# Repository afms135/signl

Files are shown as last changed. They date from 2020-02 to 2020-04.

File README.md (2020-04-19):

<p align="center">
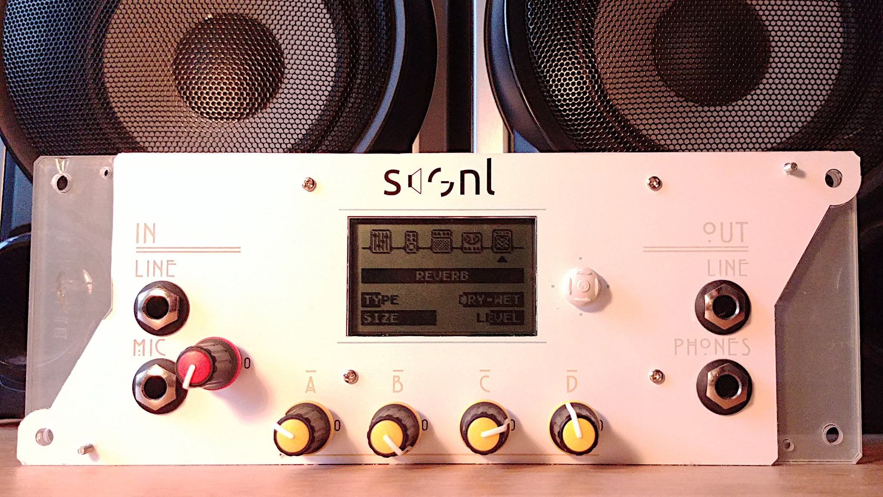
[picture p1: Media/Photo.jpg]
  
</p>

# signl - An Open Source Real-Time Audio Effects Processor running on Raspberry Pi



*signl* is an audio effects processor developed to provide an open-source (modifiable and extendable), real-time (no noticable playing latency), low-cost (Raspberry Pi based) standalone unit for musicians. Development started at the University of Glasgow for ENG5220: Real Time Embedded Programming 2019-2020.

The main features are:

* Mic or Line level in
* Line and Headphone out
* Up to five serial audio effects
* Real time parameter control of each effect
* Easy to understand GUI
* Half rack size

## Video Walkthrough

<p align="center">
  <a href="https://youtu.be/WcyoIrp74zg">
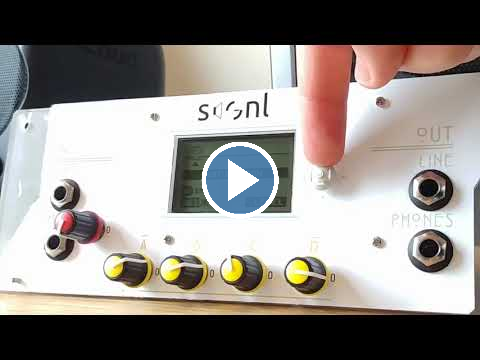
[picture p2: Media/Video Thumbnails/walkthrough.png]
  
  </a>
</p>

## Documentation

See our [Github wiki](https://github.com/afms135/signl/wiki) for detailed instructions on how to reproduce the system, as well as information about the design of the system. Detailed software documentation can be found in the [Doxygen documentation](https://afms135.github.io/signl/).

## Social Media

- [Twitter](https://twitter.com/signlHW)
- [Youtube](https://www.youtube.com/channel/UChTp4nFLsnpuzNy29fdVIeA)

## Authors and Individual Contributions

- Alexander Strachan (afms135, 2173868s) - Software Architect:  wrote hardware/JACK interface code, effect plugin system and two effects (amplifier, overdrive).
- Robert Norris (robnorr, 2198915n) - Software: Wrote GUI code (including tuner), five effects (EQ, Noise Gate, Reverb, Saturation, Vinyl), performed tests and generated data for the wiki. Contributed to the social media promotion.
- Simon Ridley (ithinkitssimon, 2187742r) - Hardware: Designed electronics and mechanical aspects of project, wrote tremolo plugin, documented relevant aspects and contributed to social media of project.

## COVID-19

The project hardware was completed before the 15th of March, so this did not prevent completion of the project, however the full project enclosure could not be manufactured. The designs for this enclosure have been included.

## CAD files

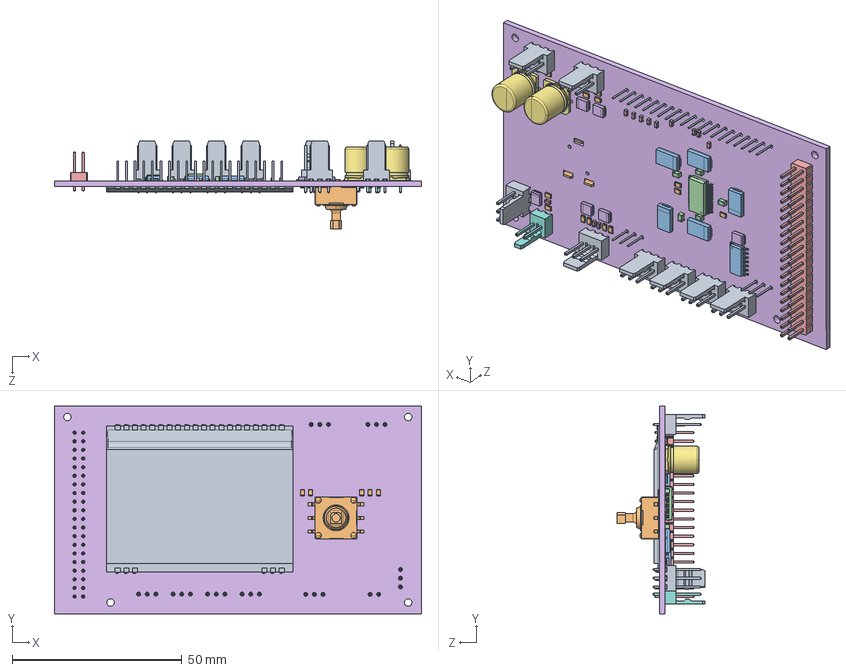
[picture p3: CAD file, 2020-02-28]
Hardware/Enclosure/Hardware.SLDASM
108.1 x 61.1 x 25.8 mm
COMPOUND.step
SOLID.step x 20
SOLID-0.step x 5
SOLID-1.step x 5
SOLID-2.step x 12
SOLID-3.step x 6
SOLID-4.step x 2
SOLID-5.step
SOLID-6.step x 8
SOLID-7.step
SOLID-8.step
SOLID-9.step
SOLID-10.step
COMPOUND-11.step

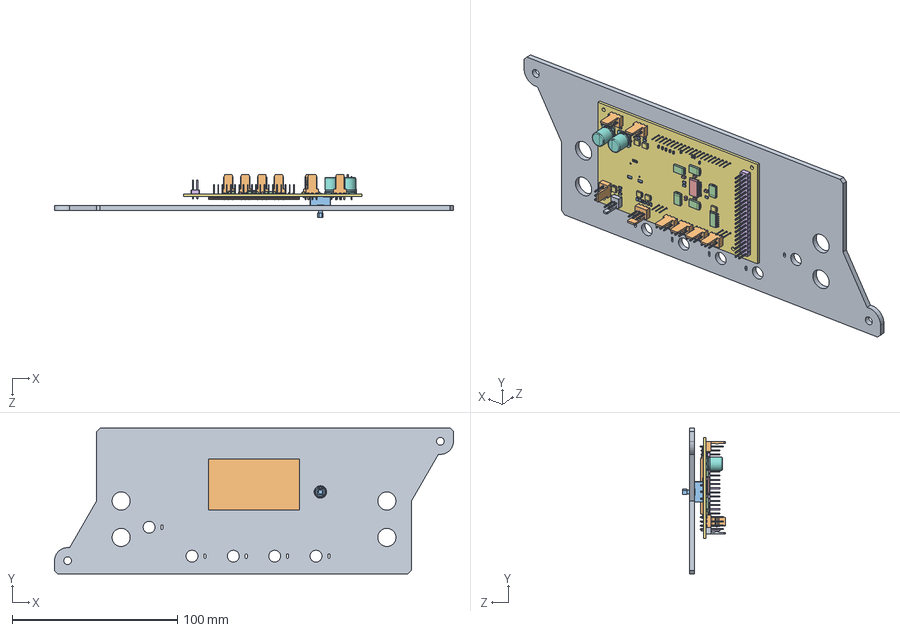
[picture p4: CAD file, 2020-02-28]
Hardware/Enclosure/Enclosure.SLDASM
241.3 x 88.1 x 25.8 mm
Faceplate
COMPOUND.step
SOLID.step x 20
SOLID-0.step x 5
SOLID-1.step x 5
SOLID-2.step x 12
SOLID-3.step x 6
SOLID-4.step x 2
SOLID-5.step
SOLID-6.step x 8
SOLID-7.step
SOLID-8.step
SOLID-9.step
SOLID-10.step
COMPOUND-11.step

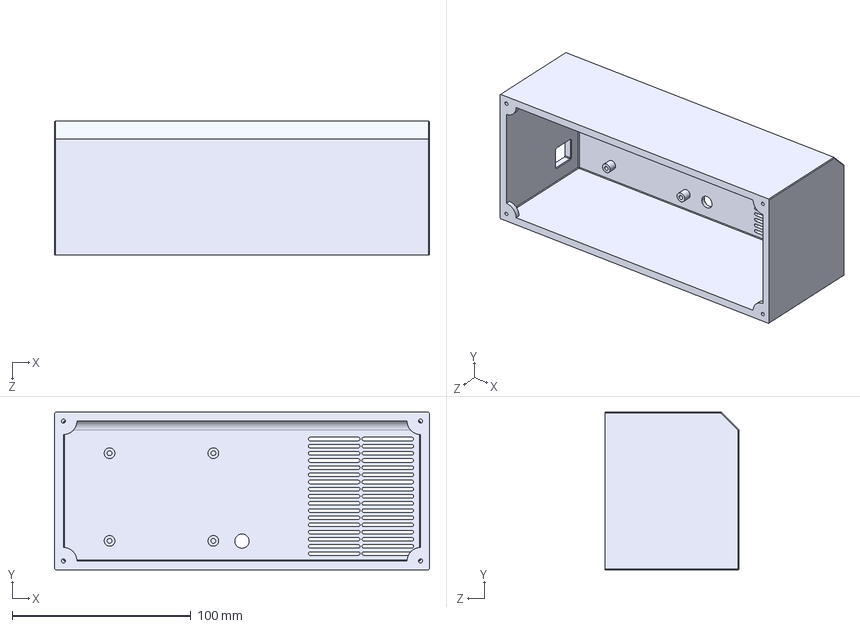
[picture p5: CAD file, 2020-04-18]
Hardware/Enclosure/Box.STEP
209.5 x 88.1 x 75.0 mm

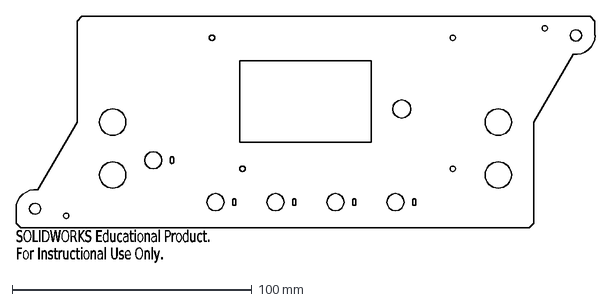
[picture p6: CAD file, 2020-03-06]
Hardware/Enclosure/FaceplateFRONT.DXF
SOLIDWORKS Educational Product.
For Instructional Use Only.

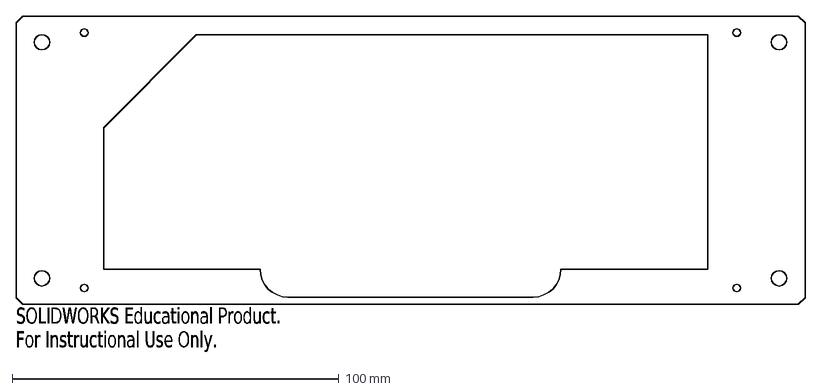
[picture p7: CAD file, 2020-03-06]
Hardware/Enclosure/FaceplateBACK.DXF
SOLIDWORKS Educational Product.
For Instructional Use Only.

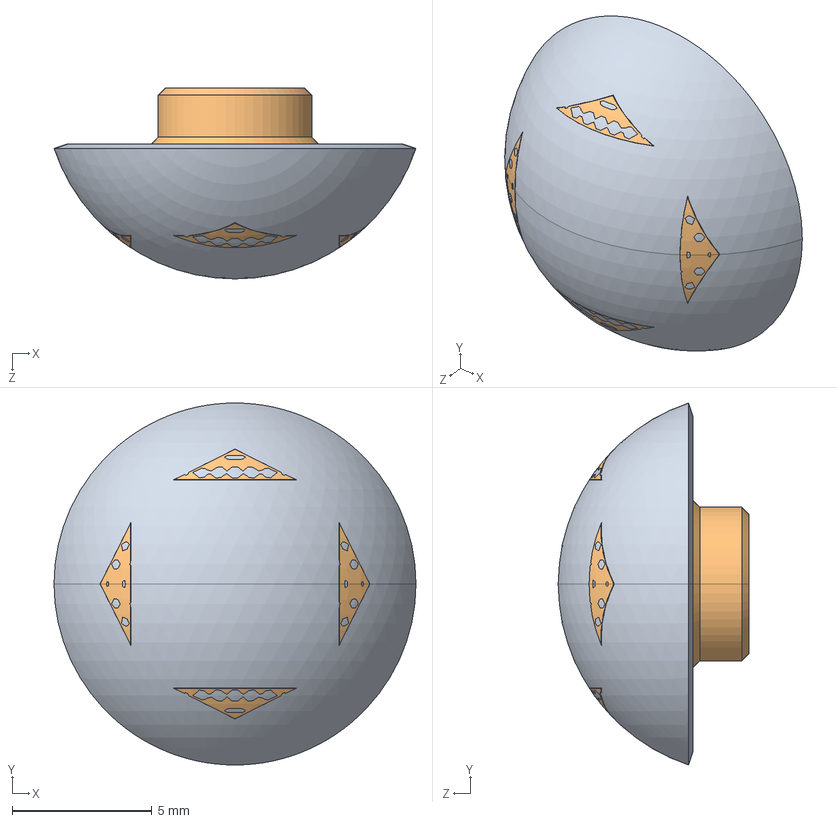
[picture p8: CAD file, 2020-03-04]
Hardware/Enclosure/JoystickButton.STEP
12.9 x 12.9 x 6.82 mm

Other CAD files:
Hardware/Enclosure/Faceplate.SLDPRT
Hardware/Enclosure/Box.SLDPRT
Hardware/Enclosure/Box.STL
Hardware/Enclosure/JoystickButton.SLDPRT
Hardware/Enclosure/JoystickButton.STL

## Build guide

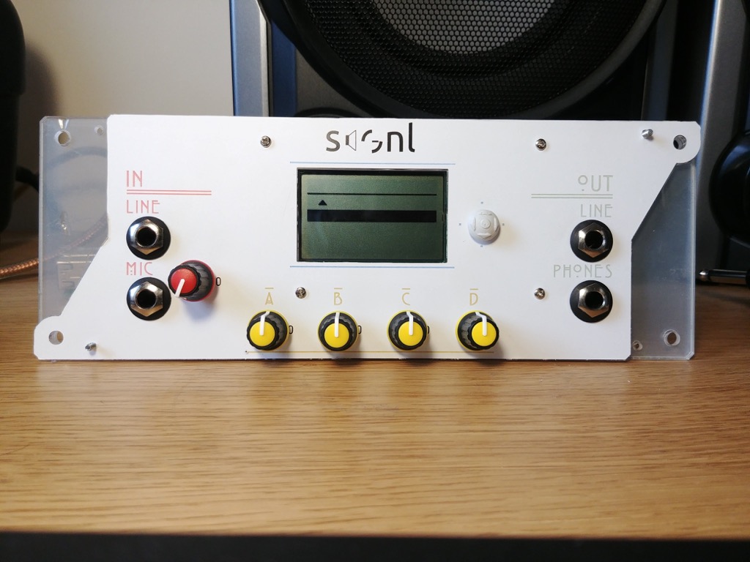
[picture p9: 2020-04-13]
Media/User Guide/user00b.jpg

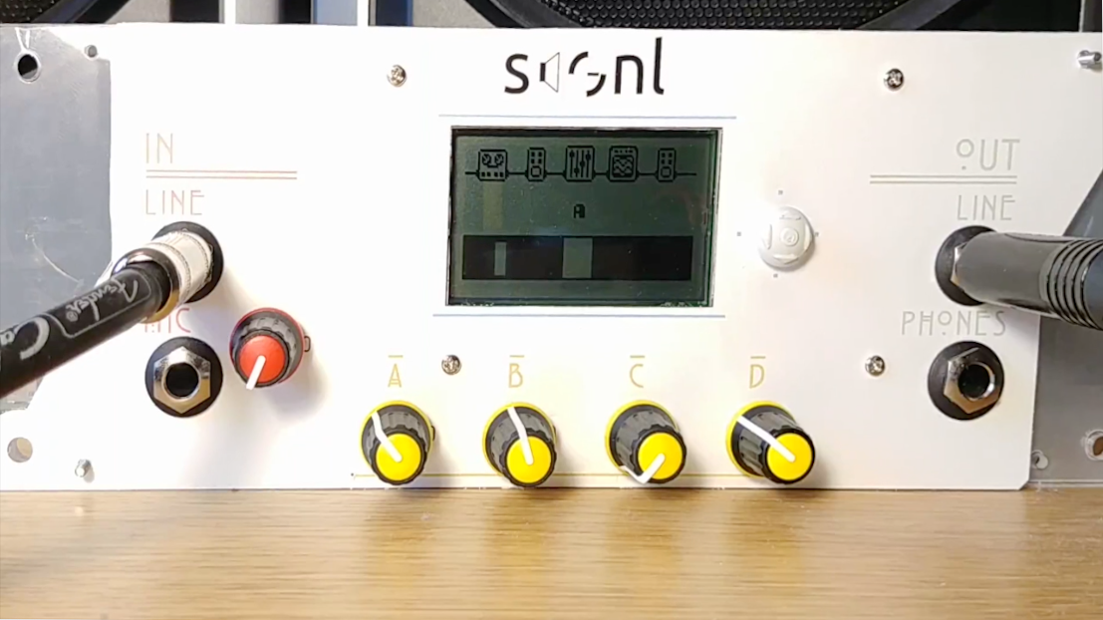
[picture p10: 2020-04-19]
Media/User Guide/user11.png

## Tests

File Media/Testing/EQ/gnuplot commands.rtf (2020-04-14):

plot "< paste L_FFT RAW_FFT" using 1:($2-$4) with filledcurve x1 linecolor "0x7Fd7191c", \
"< paste LM_FFT RAW_FFT" using 1:($2-$4) with filledcurve x1 linecolor "0x5Ffdae61", \
"< paste HM_FFT RAW_FFT" using 1:($2-$4) with filledcurve x1 linecolor "0x5fabdda4", \
"< paste H_FFT RAW_FFT" using 1:($2-$4) with filledcurve x1 linecolor "0x7F2b83ba"

set label "LOW" at 50,12 front textcolor "0xd7191c"
set label "LOW-MID" at 165,12 front textcolor "0xdd8e51"
set label "HIGH-MID" at 650,12 front textcolor "0x8bbd84"
set label "HIGH" at 3500,12 front textcolor "0x2b83ba"

plot “< paste FULL_FFT RAW_FFT" using 1:($2-$4) with filledcurve x1 linecolor "0x9FB8DE29”, \
“< paste FLAT_FFT RAW_FFT" using 1:($2-$4) with filledcurve x1 linecolor "0x3F404788"

set label "Default paramters" at 25,-10 front textcolor "0x202748"
set label "Full parameters" at 25,2 front textcolor "0x384E09"

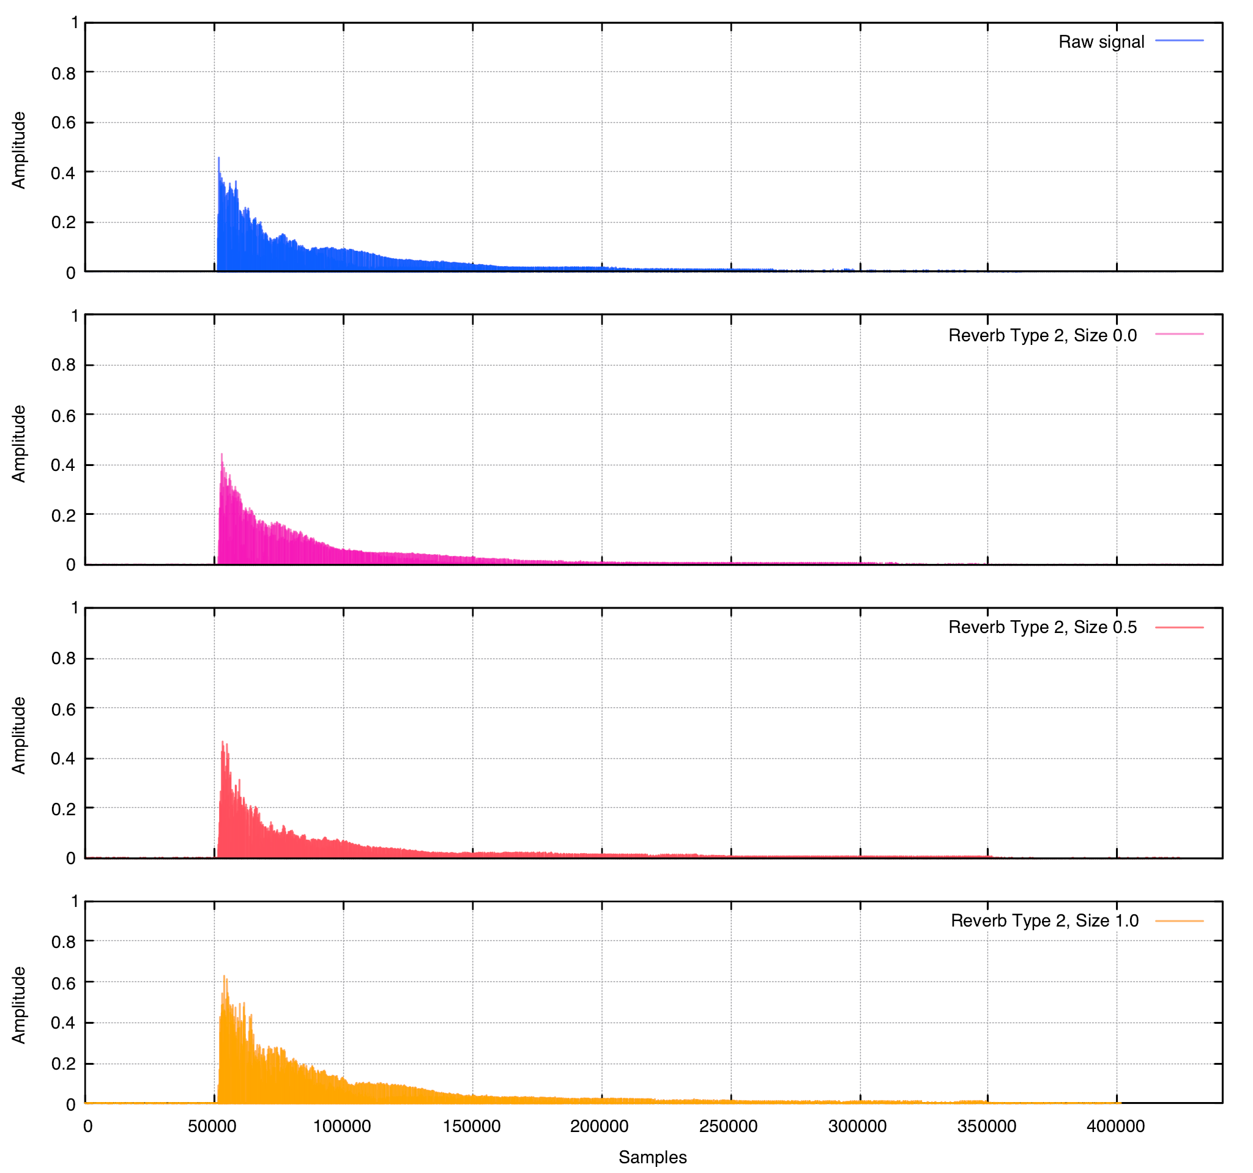
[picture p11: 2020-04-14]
Media/Testing/Reverb/Type2.png

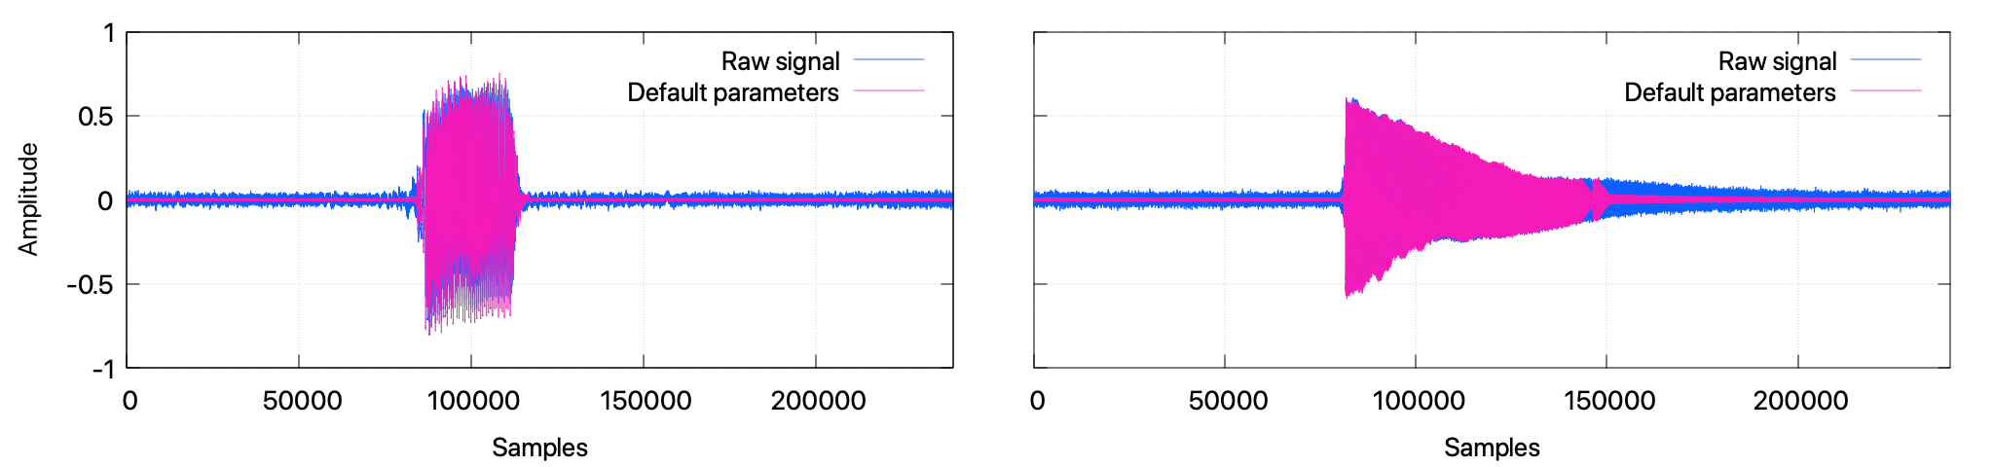
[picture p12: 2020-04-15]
Media/Testing/Noise Gate/DEF.png

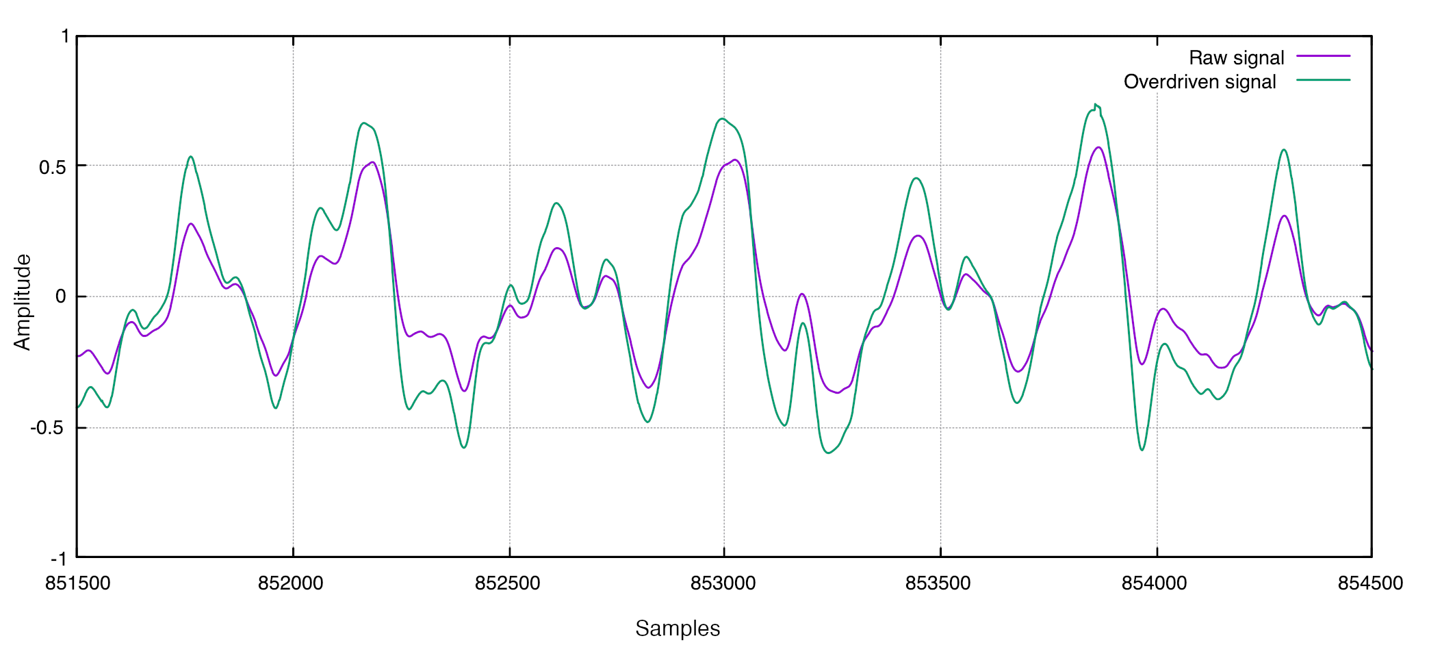
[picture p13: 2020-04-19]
Media/Testing/Overdrive/Guitar1.png

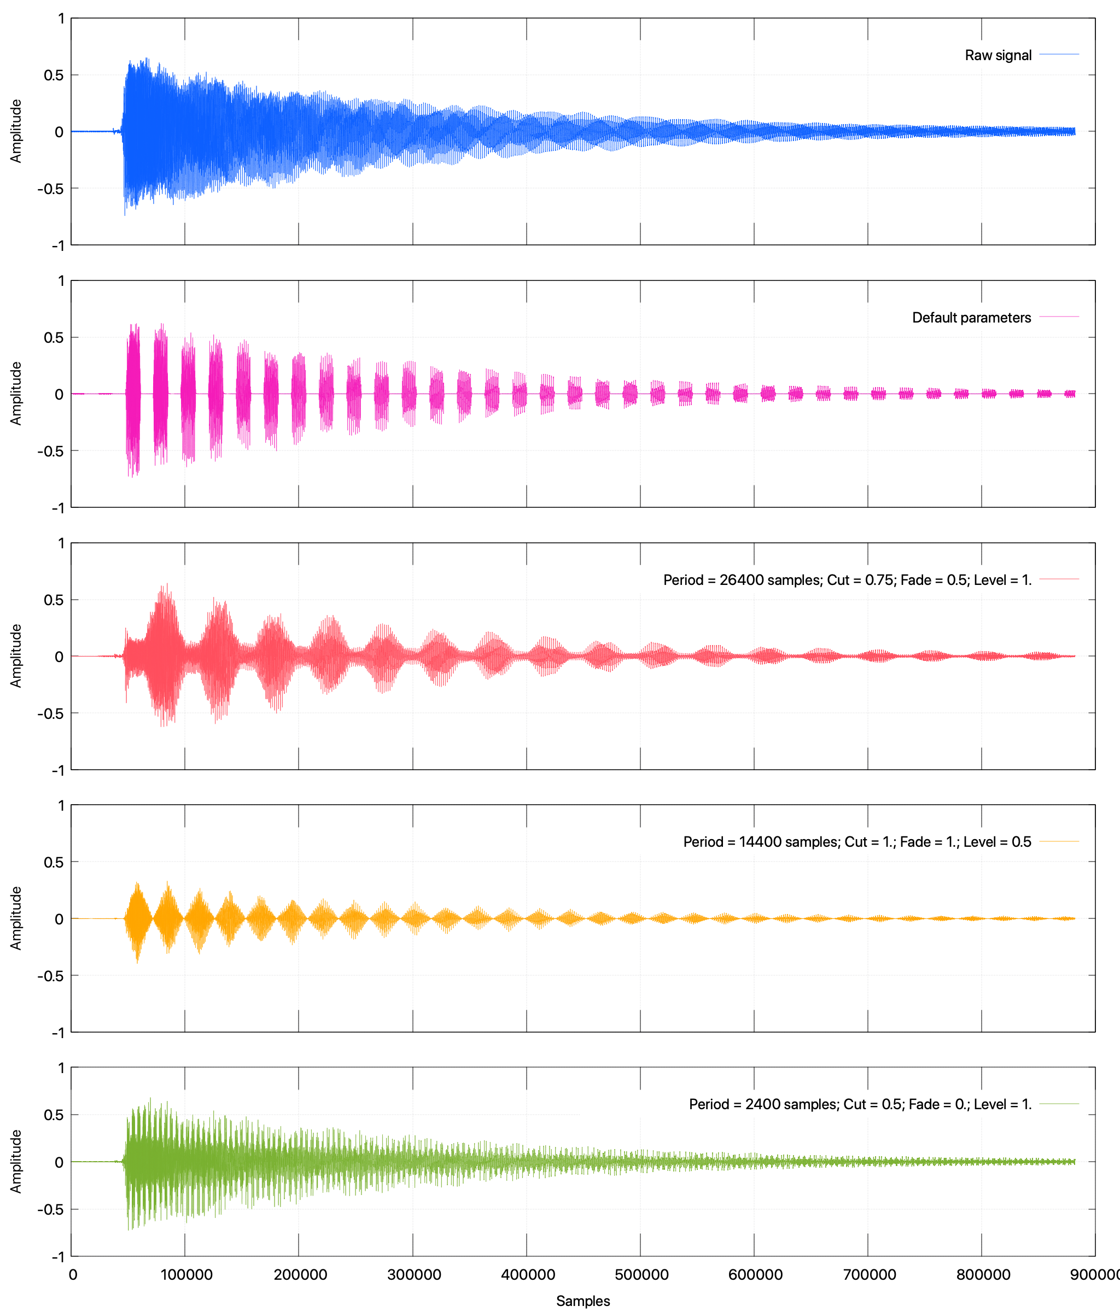
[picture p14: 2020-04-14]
Media/Testing/Tremolo/Plots.png

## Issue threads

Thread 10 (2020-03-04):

Tuner plugin

robnorr, 2020-03-04:
not sure how possible

robnorr, 2020-03-28:
Maybe better if made as another screen - via pushing the button

robnorr, 2020-04-18:
Achieved via af4ef87c2833d9f289b5b653fc9419dccaee8651
Written as a 3rd disply state (after param_view and level_view). Has a resolution of 1.46Hz

robnorr, 2020-04-18:
Not merging to master as it isn't really a useful implementation. Video and description on Wiki [here](https://github.com/afms135/signl/wiki/Tuner).

afms135, 2020-04-18:
Just copying what i said [Here](https://github.com/afms135/signl/commit/af4ef87c2833d9f289b5b653fc9419dccaee8651#comments) not sure if you get notifications.

Shouldn't line 193 of signl.cpp read fft.fft(tuner_array, fft_re.data(), fft_im.data()); You are filling tuner_array but not using it?

Would that fix the segfault?

robnorr, 2020-04-18:
Good catch! It definitely should be `fft.fft(tuner_array, ...`

But it deosn't seem to fix the segfault.

robnorr, 2020-04-18:
a5d5e1dc2916b91e8277dcb96f08fcf834b55c6b
Added gaussian interpolation and windowing inspired from [this paper](http://cds.cern.ch/record/738182/files/ab-2004-023).
Need to write up wiki (and record a demonstration video) and check that all relevant Doxygen documentation is done.

robnorr, 2020-04-19:
Closed by 7fdb2a437a745f4626878dc81359b5585256b6f4

Closed 2020-04-19.

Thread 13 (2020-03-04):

Noise gate plugin

robnorr, 2020-03-04:
Params:
Threshold
Attack
Release
Cut level

robnorr, 2020-03-08:
Closed by b7b99cb10c4ba1331b7fe238a065dc8c83ba6568

Closed 2020-03-08.

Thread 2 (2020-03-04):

EQ plugin

afms135, 2020-03-04:
Add an 4-band? equalizer plugin.

robnorr, 2020-03-04:
Or could be 3-band with the fourth parameter being the mid-freqency

robnorr, 2020-03-31:
Closed by d951ab6a34f3c8e1103f7d8e63b02f41674feea6

robnorr, 2020-03-31:
If anyone wants to reopen this issue, I believe there is a slight bump at the filter overlaps - all filters are 1st order butterworth, the xover frequencies are (150Hz, 300Hz, 3kHz). 'Low' is a lowpass, 'High' is a highpass, and the other two are bandpass. So, if there is more work to be done on this plugin, can look at the frequency response of all the filters, but for now - it works.

Closed 2020-03-31.

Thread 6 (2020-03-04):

Store current effect parameters

robnorr, 2020-03-04:
If user switches a plugin for another one, then switches back, we don't want them to have lost the parameters they had put in previously.

robnorr, 2020-03-04:
This should also help with presets if we end up doing that.

robnorr, 2020-03-20:
Have somewhat fixed this with a6fb38cac325e3de6108d7da31902e091f61844e and 34ad3bb21003db3555e952cdbe3c1dfca51d5a70

Closed 2020-04-14.

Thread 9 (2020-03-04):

Tremolo plugin

robnorr, 2020-03-04:
Params:
Rate
Depth
Fade
Level

ithinkitssimon, 2020-04-09:
Started new branch for tremolo plugin.

robnorr, 2020-04-09:
Period and cut work, but fade is broken.

ithinkitssimon, 2020-04-09:
Closed by cde07c1253e88e85d771904e55b5b538eec5e8da

Closed 2020-04-09.

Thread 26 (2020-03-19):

JACK crashing on entry

robnorr, 2020-03-19:
Wasn't doing this before - can't see any changes hardware wise. Tried power cycle with same thing happening. Any ideas?

Ouput log

```
pi@raspberrypi:~ $ JACK_NO_AUDIO_RESERVATION=1 jackd -P75 -dalsa -dhw:0 -r48000 -p256 -n2
jackdmp 1.9.12
Copyright 2001-2005 Paul Davis and others.
Copyright 2004-2016 Grame.
Copyright 2016-2017 Filipe Coelho.
jackdmp comes with ABSOLUTELY NO WARRANTY
This is free software, and you are welcome to redistribute it
under certain conditions; see the file COPYING for details
JACK server starting in realtime mode with priority 75
self-connect-mode is "Don't restrict self connect requests"
creating alsa driver ... hw:0|hw:0|256|2|48000|0|0|nomon|swmeter|-|32bit
configuring for 48000Hz, period = 256 frames (5.3 ms), buffer = 2 periods
ALSA: final selected sample format for capture: 32bit integer little-endian
ALSA: use 2 periods for capture
ALSA: final selected sample format for playback: 32bit integer little-endian
ALSA: use 2 periods for playback
ALSA: poll time out, polled for 7999098 usecs
JackAudioDriver::ProcessAsync: read error, stopping...
```

robnorr, 2020-03-19:
Update - doesn't do it every time. Works sometimes but not always.

robnorr, 2020-03-25:
This is getting worse. Jackd almost always crashes, always with the same output log as above, but I can't figure out what is different when it works - seems totally random. Getting very hard to get any work done when I can't get any audio out.

Very rarely, when jackd doesn't crash straight away (after its 8sec timeout), I can run the signl software, but then often it just crashes: sometimes when I do something like change an effect; sometimes just randomly.

Have tried various alsamixer settings, but they don't appear to make any difference - have tried both line in and mic in as the input mux but same timeout error occurs. Have tried different jackd buffer sizes, periods, etc. - the only thing that changes is that the period length seems proportional to the timeout.

robnorr, 2020-03-26:
Seems it was a hardware issue - intermittent connection to the external crystal. Working now.

Closed 2020-03-26.

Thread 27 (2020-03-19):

ADC values return 0

robnorr, 2020-03-19:
Have checked voltage on the pins of the ADC (MCP3004) - they are what they should be. But the SPI transfer is returning 0 no matter what.

ithinkitssimon, 2020-03-19:
Have you checked CS line?

afms135, 2020-03-20:
Try reducing the SPI clock rate to 1000000 (or lower).
I think 2000000 might be to high (line 4 of adc.cpp).

robnorr, 2020-03-20:
> Have you checked CS line?

On program start up, chip select goes high, then low. The first value read from the ADC works properly, but the chip select never goes high again therefore the rest of the values read are all 0.

So, need to figure out why the chip select line is getting stuck low.

robnorr, 2020-03-20:
Closed by 1cb5aca4819267a3845c9bf30a77d94539ea7d11

Closed 2020-03-20.

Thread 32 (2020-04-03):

Buffer based

robnorr, 2020-04-03:
Tried to send audio buffers straight from jack to each plugin as it's the more normal way of operating when doing audio stuff. But mainly tried it to halve the latency of the convolution plugin.

Tried on a new branch here bd3dcbe66a859814dcbf2434dfa134225c111fe3

And while it compiles and runs - can even see that audio is going through properly - the line out is silent. No idea why.

afms135, 2020-04-03:
This doesn't work because the `*out` pointer that jack gives us is a buffer that you need to _write_ into.
So swapping the pointers like in the null plugin won't work. Basically the operator signiture would need to be changed to `void operator()(float *in, float *out, unsigned int frames)` and the jack->signl callback
would need to be changed to `virtual void process(sample_t* in, sample_t *out, jack_nframes_t frames) = 0;`

robnorr, 2020-04-03:
That makes sense. I've decided it's fine to leave it as it is (non-buffer based), because it gives more flexibility to those plugins that do need buffers (i.e. convolution) over the buffer size etc. At the cost of double latency, but that's okay for now, and probably will be forever (I hope)

afms135, 2020-04-10:
Should we close this? It can always be reopened if necessary.

Closed 2020-04-10.

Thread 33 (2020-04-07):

Deleting the reverb plugin crashes the signl software

robnorr, 2020-04-07:
If the reverb plugin is being used (see 7ae3209015648144f1a2c41f5cef258c4c02af92 ), and is then deleted (i.e., switched out for another plugin), the signl software crashes and stops, with this being spat out on the terminal:

    signl: ../FFTConvolver/Utilities.cpp:61: void fftconvolver::ComplexMultiplyAccumulate(fftconvolver::SplitComplex&, const fftconvolver::SplitComplex&, const fftconvolver::SplitComplex&): Assertion `result.size() == b.size()' failed.
    Aborted

My guess is that the FFTConvolver object(s) which are created in the reverb plugin aren't destroyed properly, but I can't figure out how to destroy them properly.

afms135, 2020-04-07:
Reorder the classes private members, they are destructed in reverse order. The problem probably is the std::vectors are being destroyed before the FFTConvolvers, so try placing the convolves last.

afms135, 2020-04-07:
See a80ed9f68adab00561acb64b48f637278658d37a

robnorr, 2020-04-07:
Okay, odd behaviour now. Have made the change you suggested, and the problem is fixed for the first time that I switch out the reverb plugin (i.e. it no longer crashes). But, if the plugin is put back in, this time (and for every time after) when I switch it out, it crashes the same way as before.

robnorr, 2020-04-07:
Note, sometimes it crashes with `Segmentation fault` rather than the above message.

robnorr, 2020-04-07:
Okay, I tried with just one FFTConvolver at a time and it seems like it was the big long church IR (131,072 samples) that was causing problems. The smaller IR (16,384 samples) on its own never crashes.

robnorr, 2020-04-07:
Using the TwoStageFFTConvolver has greatly improved this. Still crashes sometimes, but FAR less often.

afms135, 2020-04-07:
Maybe try changing the type of the impulse arrays to const float[] instead of a vector. But my gut feeling for a long term fix is to compile the fftconvolver code _into_ the so file instead of using dlopen() to load it into the main executable. That would require a makefile change, but I'd rather wait until the plugin is finished before doing that.

robnorr, 2020-04-07:
Seems pretty stable now. Can only make it crash by switching between the reverb and some other effect really fast repeatedly. But what you say might help, so I'll let you know when I've finished the rest of the plugin

robnorr, 2020-04-08:
Reverb plugin is finished and ready to be merged as of e27cc37cb5b124e46912d815ed9ad1e6a67f0beb .

It only crashes if you switch it out within ~1 sec of switching onto it, but other than that it's perfect.
@afms135 would you rather I merge to master now, or do you want to make any changes in the branch?

afms135, 2020-04-08:
Do the merge now, I'll do my work later.

afms135, 2020-04-14:
Fixed by 7207acab2960d0daf7a8058055e3c33809f3bd66

Closed 2020-04-14.

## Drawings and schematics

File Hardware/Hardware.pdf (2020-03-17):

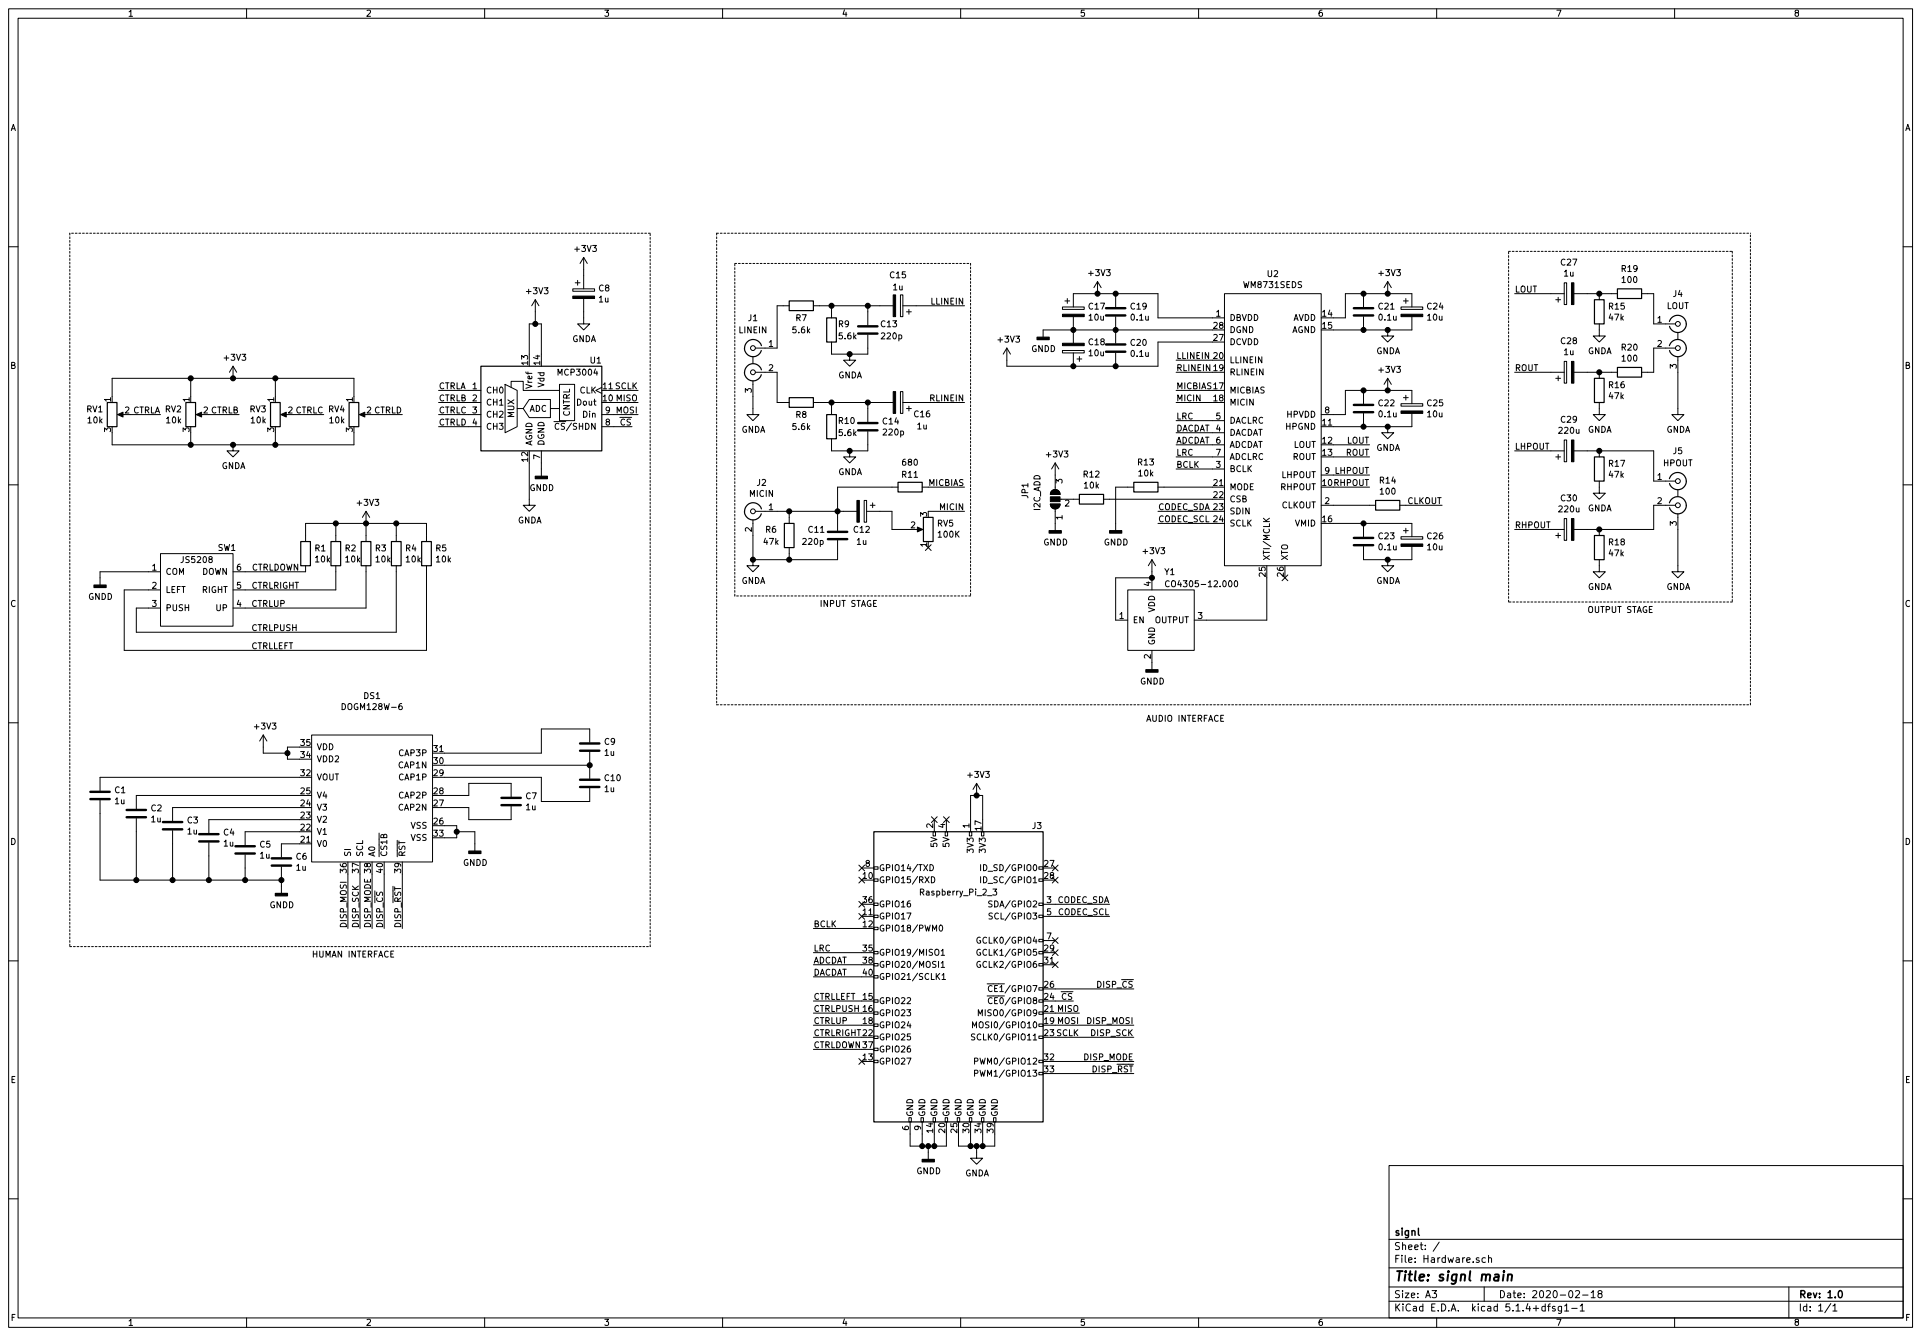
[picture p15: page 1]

7 CS/SHDN 8 Din 9 U1 MCP3004 +3V3 GNDD

LRC MICIN
LRC
LHPOUT LOUT ROUT DACDAT ADCDAT

AUDIO INTERFACE HUMAN INTERFACE

CTRLRIGHT CTRLUP CTRLLEFT CTRLPUSH

File: Hardware.sch Sheet: / signl

Id: 1/1 Title: signl main

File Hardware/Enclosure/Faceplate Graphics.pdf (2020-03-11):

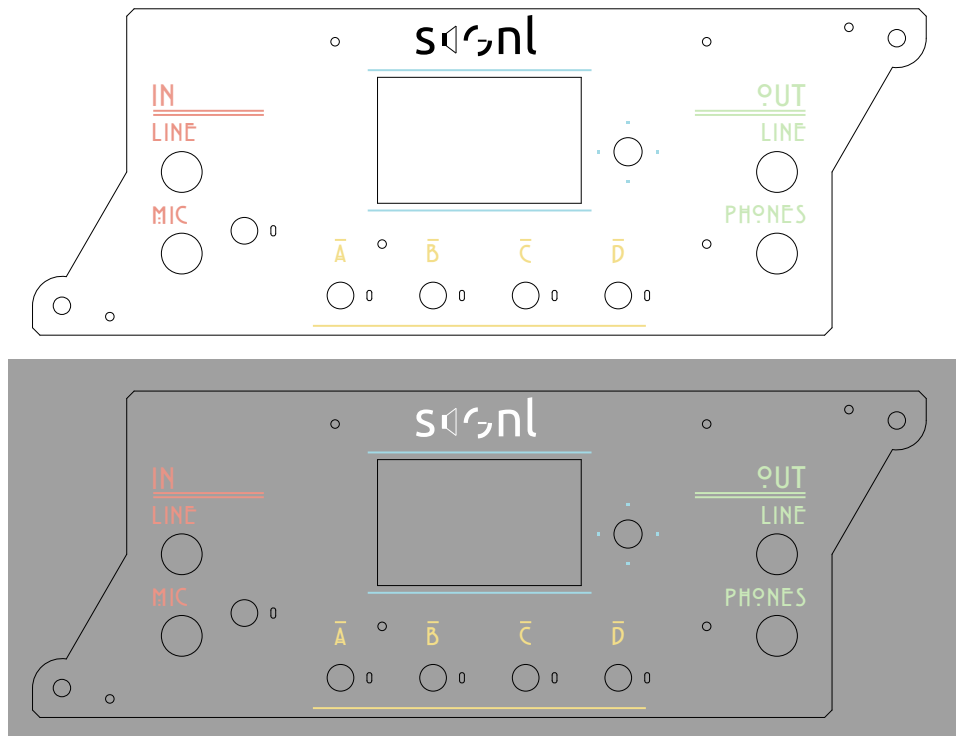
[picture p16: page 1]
LINE; MIC; PHONES A; OUT

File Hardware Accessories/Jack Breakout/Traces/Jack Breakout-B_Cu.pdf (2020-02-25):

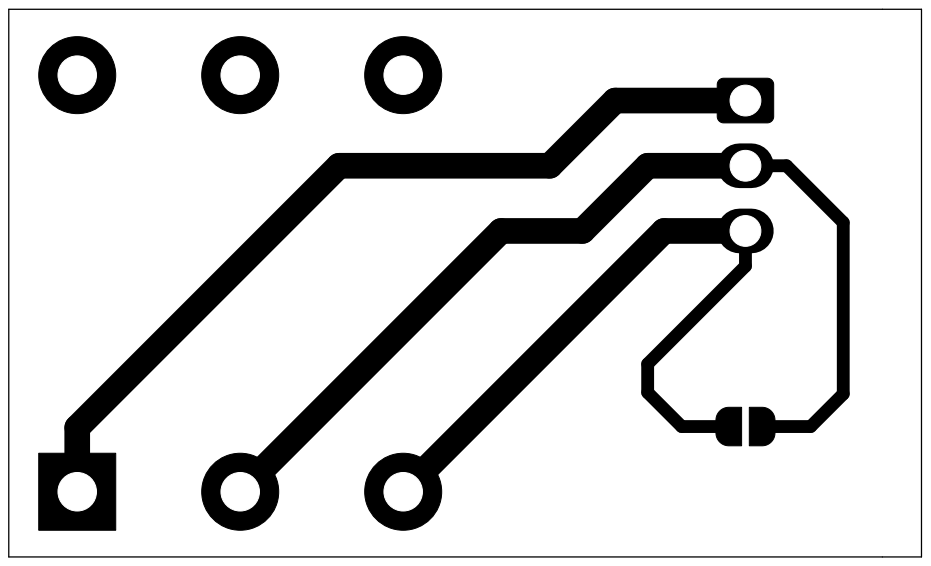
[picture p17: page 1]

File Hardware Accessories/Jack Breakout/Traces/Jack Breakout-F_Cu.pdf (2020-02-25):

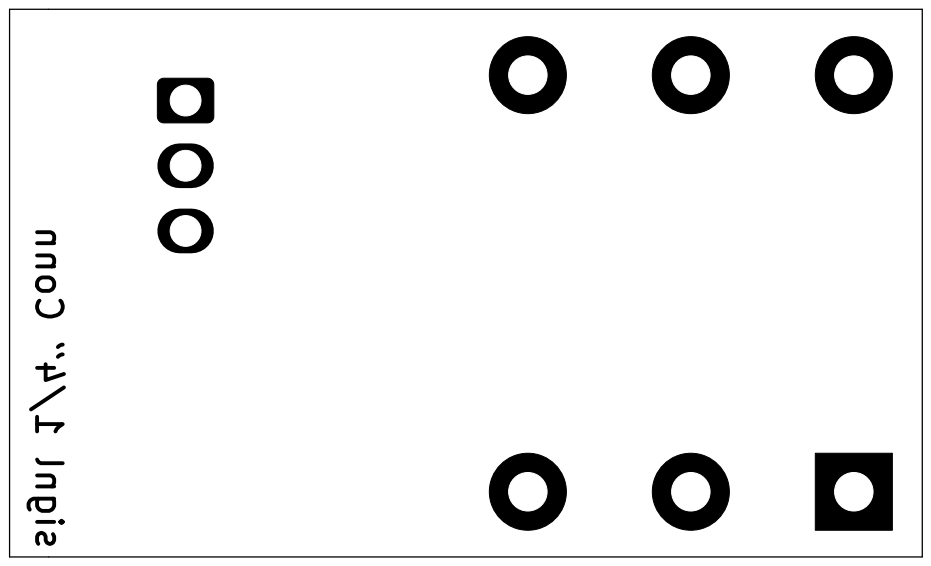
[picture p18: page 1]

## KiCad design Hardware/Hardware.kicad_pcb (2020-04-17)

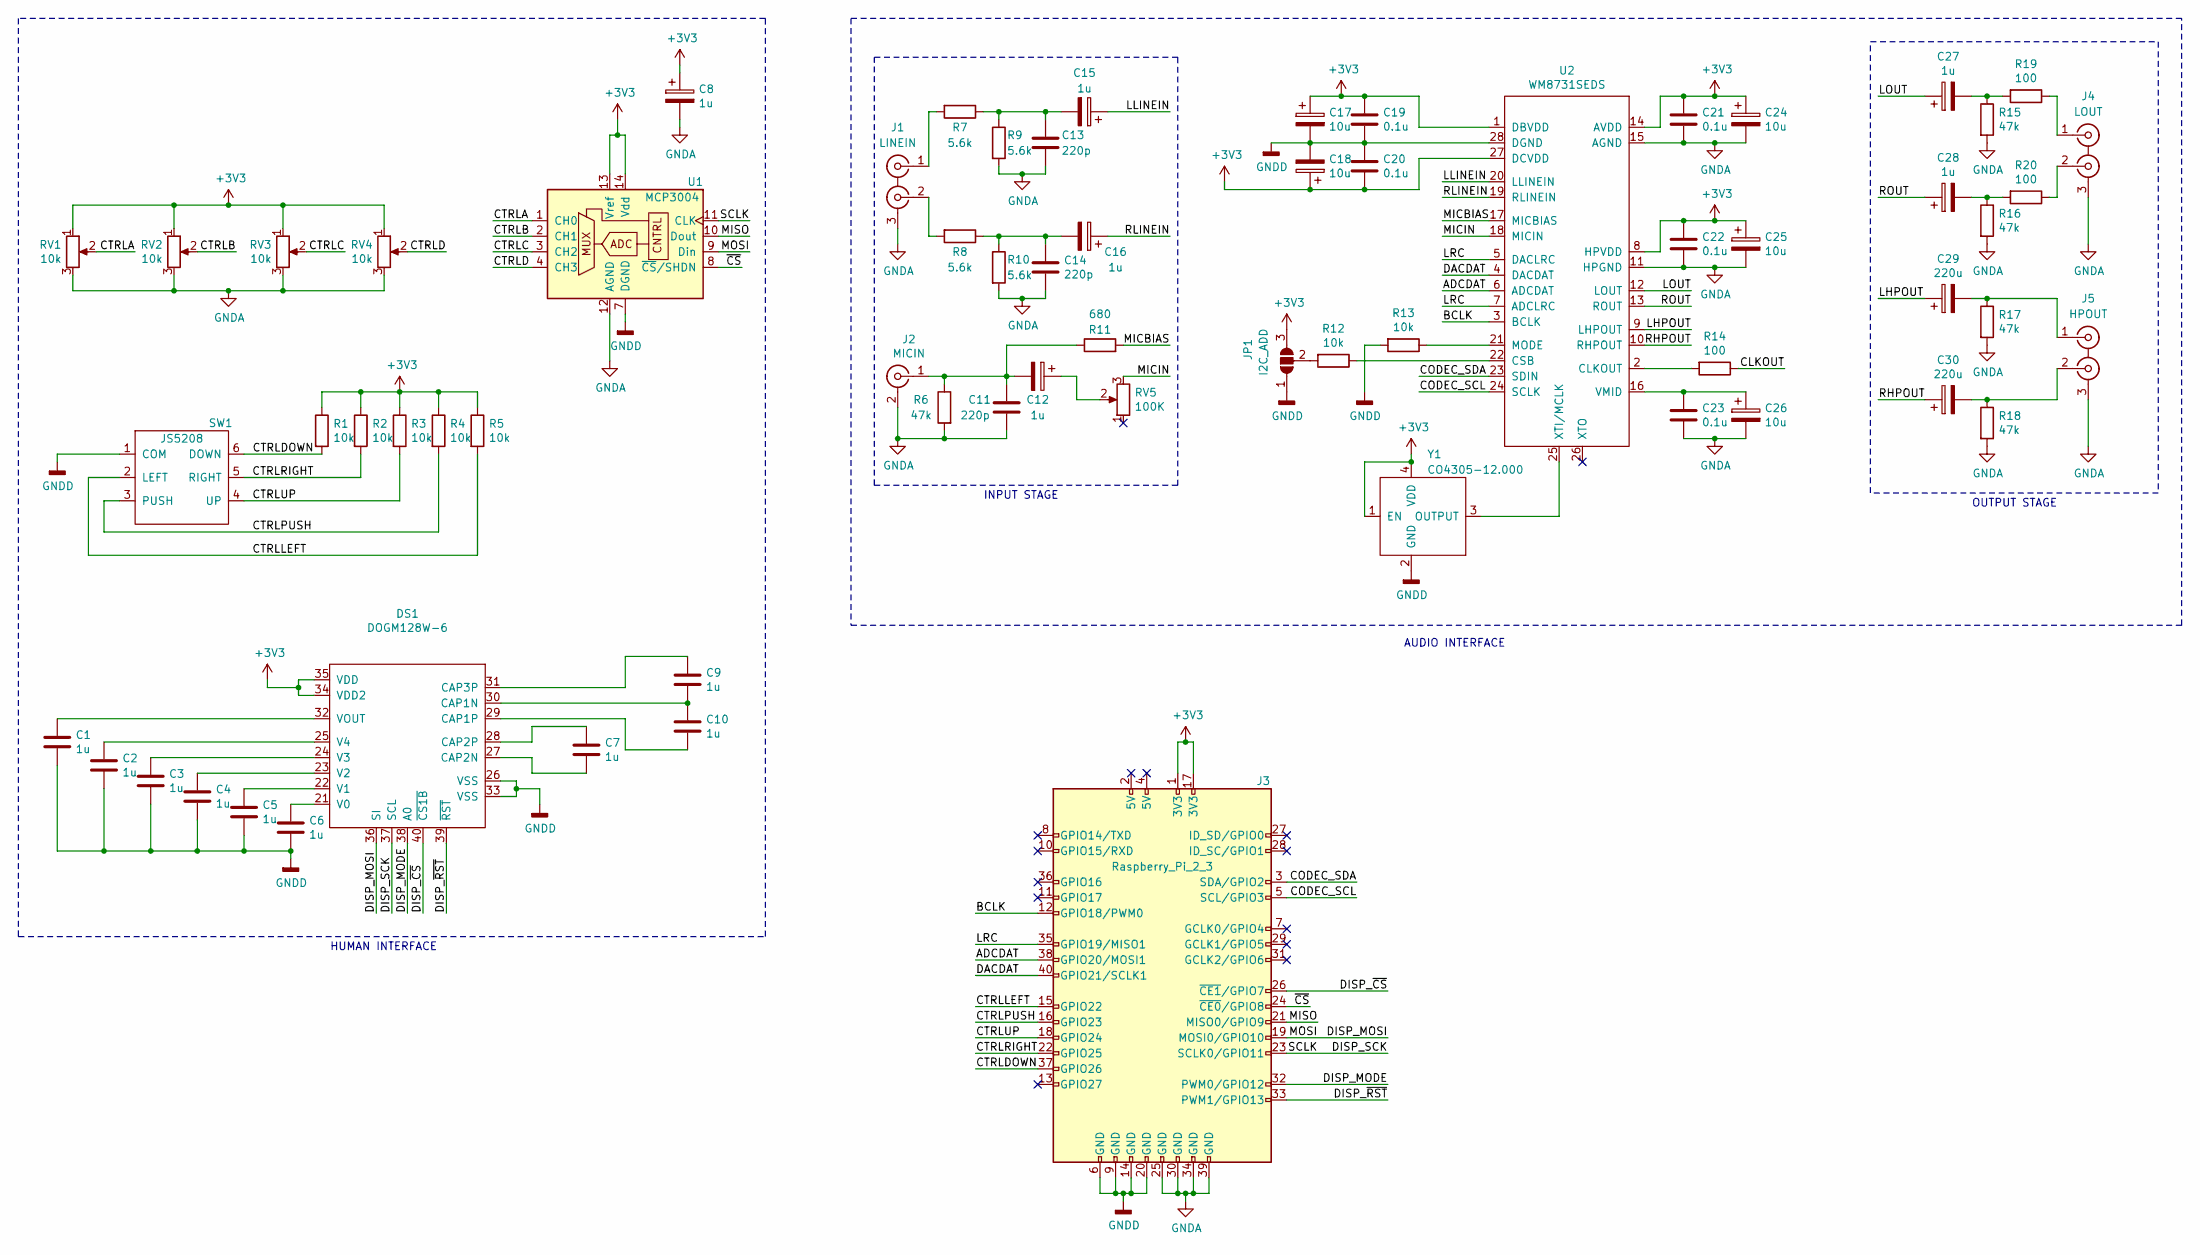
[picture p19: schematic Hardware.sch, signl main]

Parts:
C1, C2, C3, C4, C5, C6, C7, C9, C10: 1u; C_0603_1608Metric_Pad1.05x0.95mm_HandSolder
C8, C12, C15, C16, C27, C28: 1u; CP_EIA-3528-12_Kemet-T_Pad1.50x2.35mm_HandSolder
C11, C13, C14: 220p; C_0603_1608Metric_Pad1.05x0.95mm_HandSolder
C17, C18, C24, C25, C26: 10u; CP_EIA-7343-15_Kemet-W_Pad2.25x2.55mm_HandSolder
C19, C20, C21, C22, C23: 0.1u; C_0805_2012Metric_Pad1.15x1.40mm_HandSolder
C29, C30: 220u; CP_Elec_8x10
DS1: DOGM128W-6; DOGM128W
J1: LINEIN; Molex_KK-254_AE-6410-03A_1x03_P2.54mm_Vertical
J2: MICIN; Molex_KK-254_AE-6410-02A_1x02_P2.54mm_Vertical
J3: Raspberry_Pi_2_3; PinHeader_2x20_P2.54mm_Vertical
J4: LOUT; Molex_KK-254_AE-6410-03A_1x03_P2.54mm_Vertical
J5: HPOUT; Molex_KK-254_AE-6410-03A_1x03_P2.54mm_Vertical
JP1: I2C_ADD; SolderJumper-3_P1.3mm_Open_RoundedPad1.0x1.5mm_NumberLabels
R1, R2, R3, R4, R5, R12, R13: 10k; R_0805_2012Metric_Pad1.15x1.40mm_HandSolder
R6, R15, R16, R17, R18: 47k; R_0805_2012Metric_Pad1.15x1.40mm_HandSolder
R7, R8, R9, R10: 5.6k; R_0805_2012Metric_Pad1.15x1.40mm_HandSolder
R11: 680; R_0805_2012Metric_Pad1.15x1.40mm_HandSolder
R14, R19, R20: 100; R_0805_2012Metric_Pad1.15x1.40mm_HandSolder
RV1, RV2, RV3, RV4: 10k; Molex_KK-254_AE-6410-03A_1x03_P2.54mm_Vertical
RV5: 100K; Molex_KK-254_AE-6410-03A_1x03_P2.54mm_Vertical
SW1: JS5208
U1: MCP3004; SOIC-14_3.9x8.7mm_P1.27mm
U2: WM8731SEDS; SSOP-28_5.3x10.2mm_P0.65mm
Y1: CO4305-12.000

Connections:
+3V3: C8.1, C17.1, C18.1, C19.1, C20.2, C21.1, C22.1, C24.1, C25.1, DS1.34 (VDD2), DS1.35 (VDD), J3.1 (3V3), J3.17 (3V3), JP1.3 (B), R1.1, R2.1, R3.1, R4.1, R5.1, RV1.1, RV2.1, RV3.1, RV4.1, U1.13 (Vref), U1.14 (Vdd), U2.1 (DBVDD), U2.8 (HPVDD), U2.14 (AVDD), U2.27 (DCVDD), Y1.1 (EN), Y1.4 (VDD)
/ADCDAT: J3.38 (GPIO20/MOSI1), U2.6 (ADCDAT)
/BCLK: J3.12 (GPIO18/PWM0), U2.3 (BCLK)
/CLKOUT: R14.1
/CODEC_SCL: J3.5 (SCL/GPIO3), U2.24 (SCLK)
/CODEC_SDA: J3.3 (SDA/GPIO2), U2.23 (SDIN)
/CTRLA: RV1.2, U1.1 (CH0)
/CTRLB: RV2.2, U1.2 (CH1)
/CTRLC: RV3.2, U1.3 (CH2)
/CTRLD: RV4.2, U1.4 (CH3)
/CTRLDOWN: J3.37 (GPIO26), R1.2, SW1.6 (DOWN)
/CTRLLEFT: J3.15 (GPIO22), R5.2, SW1.2 (LEFT)
/CTRLPUSH: J3.16 (GPIO23), R4.2, SW1.3 (PUSH)
/CTRLRIGHT: J3.22 (GPIO25), R2.2, SW1.5 (RIGHT)
/CTRLUP: J3.18 (GPIO24), R3.2, SW1.4 (UP)
/DACDAT: J3.40 (GPIO21/SCLK1), U2.4 (DACDAT)
/DISP_MODE: DS1.38 (A0), J3.32 (PWM0/GPIO12)
/DISP_MOSI: DS1.36 (SI), J3.19 (MOSI0/GPIO10), U1.9 (Din)
/DISP_SCK: DS1.37 (SCL), J3.23 (SCLK0/GPIO11), U1.11 (CLK)
/DISP_~CS~: DS1.40 (~CS1B~), J3.26 (~CE1~/GPIO7)
/DISP_~RST~: DS1.39 (~RST~), J3.33 (PWM1/GPIO13)
/LHPOUT: C29.1, U2.9 (LHPOUT)
/LLINEIN: C15.1, U2.20 (LLINEIN)
/LOUT: C27.1, U2.12 (LOUT)
/LRC: J3.35 (GPIO19/MISO1), U2.5 (DACLRC), U2.7 (ADCLRC)
/MICBIAS: R11.2, U2.17 (MICBIAS)
/MICIN: RV5.3, U2.18 (MICIN)
/MISO: J3.21 (MISO0/GPIO9), U1.10 (Dout)
/RHPOUT: C30.1, U2.10 (RHPOUT)
/RLINEIN: C16.1, U2.19 (RLINEIN)
/ROUT: C28.1, U2.13 (ROUT)
/~CS~: J3.24 (~CE0~/GPIO8), U1.8 (~CS~/SHDN)
GNDA: C8.2, C11.2, C13.2, C14.2, C21.2, C22.2, C23.2, C24.2, C25.2, C26.2, J1.3 (EXT), J2.2 (Ext), J3.25 (GND), J3.30 (GND), J3.34 (GND), J3.39 (GND), J4.3 (EXT), J5.3 (EXT), R6.2, R9.2, R10.2, R15.2, R16.2, R17.2, R18.2, RV1.3, RV2.3, RV3.3, RV4.3, U1.12 (AGND), U2.11 (HPGND), U2.15 (AGND)
GNDD: C1.2, C2.2, C3.2, C4.2, C5.2, C6.2, C17.2, C18.2, C19.2, C20.1, DS1.26 (VSS), DS1.33 (VSS), J3.6 (GND), J3.9 (GND), J3.14 (GND), J3.20 (GND), JP1.1 (A), R13.2, SW1.1 (COM), U1.7 (DGND), U2.28 (DGND), Y1.2 (GND)
unnamed: C1.1, DS1.32 (VOUT)
unnamed: C2.1, DS1.25 (V4)
unnamed: C3.1, DS1.24 (V3)
unnamed: C4.1, DS1.23 (V2)
unnamed: C5.1, DS1.22 (V1)
unnamed: C6.1, DS1.21 (V0)
unnamed: C7.1, DS1.28 (CAP2P)
unnamed: C7.2, DS1.27 (CAP2N)
unnamed: C9.1, DS1.31 (CAP3P)
unnamed: C9.2, C10.1, DS1.30 (CAP1N)
unnamed: C10.2, DS1.29 (CAP1P)
unnamed: C11.1, C12.2, J2.1 (In), R6.1, R11.1
unnamed: C12.1, RV5.2
unnamed: C13.1, C15.2, R7.1, R9.1
unnamed: C14.1, C16.2, R8.1, R10.1
unnamed: C23.1, C26.1, U2.16 (VMID)
unnamed: C27.2, R15.1, R19.2
unnamed: C28.2, R16.1, R20.2
unnamed: C29.2, J5.1 (IN1), R17.1
unnamed: C30.2, J5.2 (IN2), R18.1
unnamed: DS1.1 (A1), DS1.2 (A2), DS1.3 (A3), DS1.18 (C1), DS1.19 (C2), DS1.20 (C3)
unnamed: J1.1 (IN1), R7.2
unnamed: J1.2 (IN2), R8.2
unnamed: J4.1 (IN1), R19.1
unnamed: J4.2 (IN2), R20.1
unnamed: JP1.2 (C), R12.2
unnamed: R12.1, U2.22 (CSB)
unnamed: R13.1, U2.21 (MODE)
unnamed: R14.2, U2.2 (CLKOUT)
unnamed: U2.25 (XTI/MCLK), Y1.3 (OUTPUT)

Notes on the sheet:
OUTPUT STAGE
INPUT STAGE
HUMAN INTERFACE
AUDIO INTERFACE

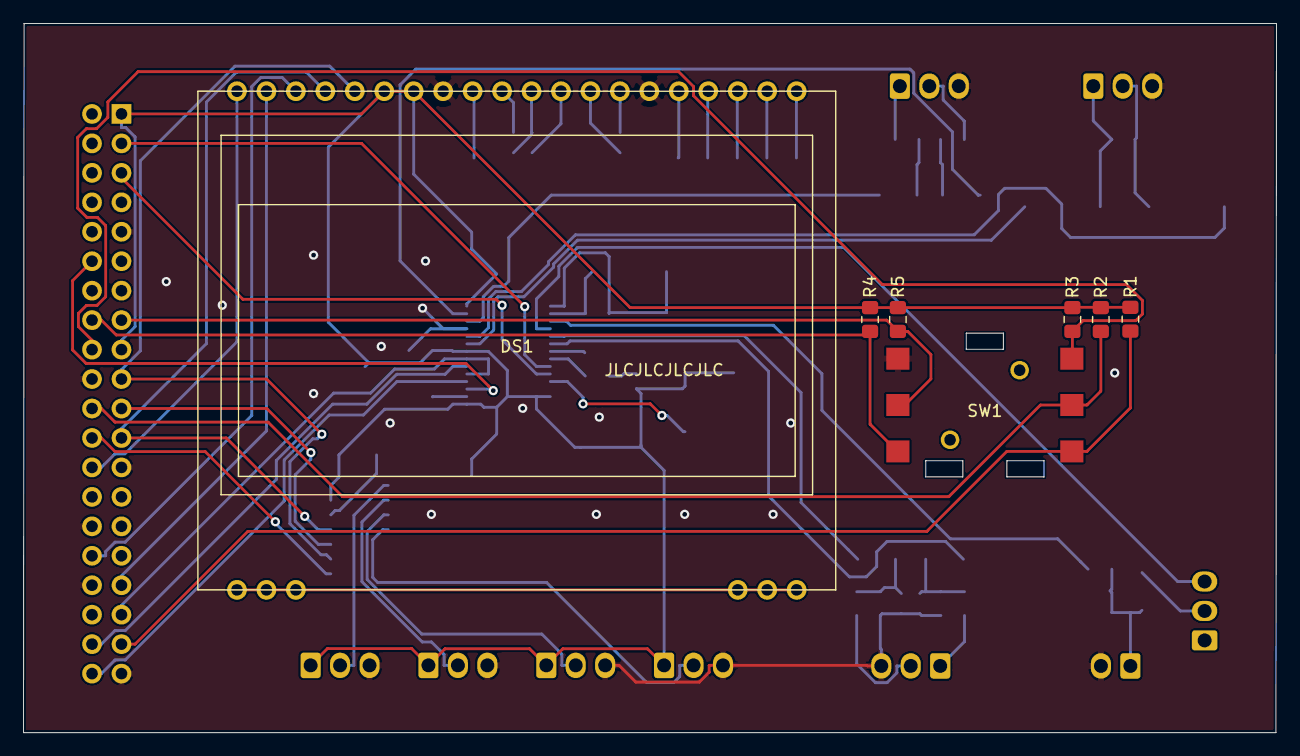
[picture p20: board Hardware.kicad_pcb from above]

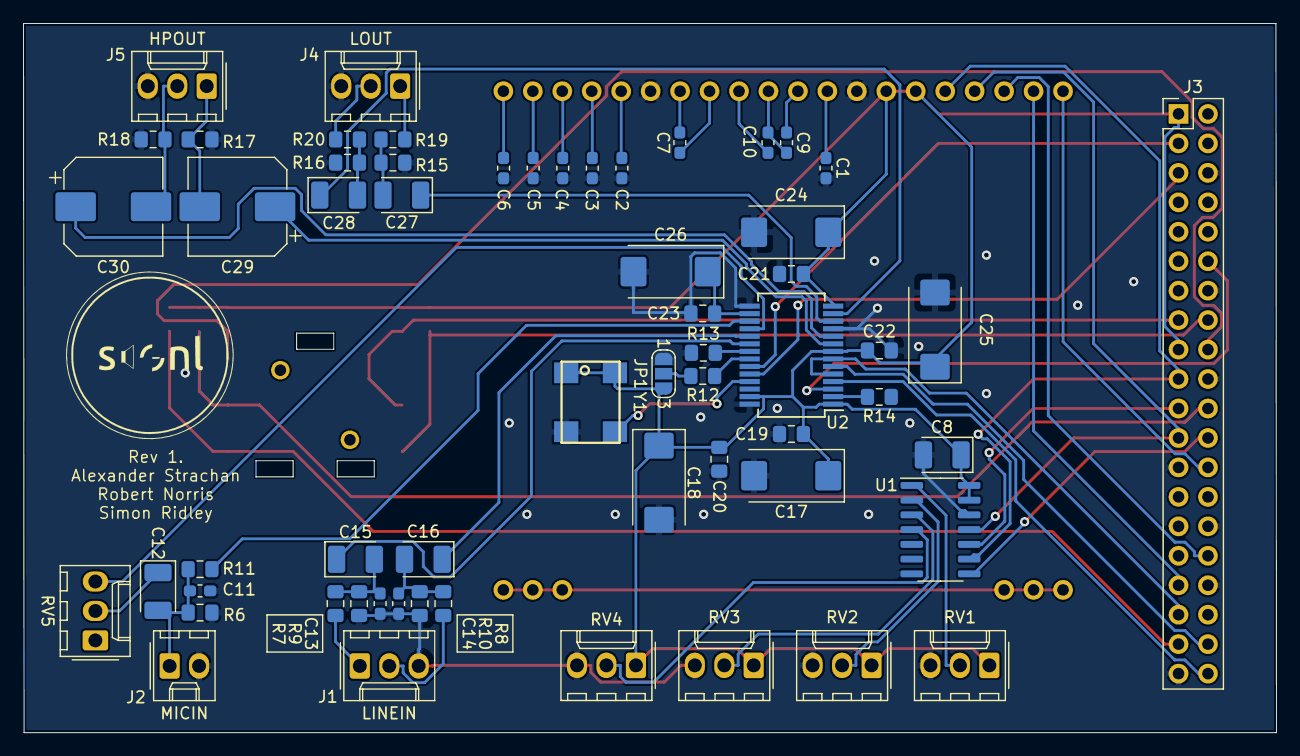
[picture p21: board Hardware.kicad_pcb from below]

Board: 2 copper layers, 108.0 x 61.2 mm, 66 parts (59 on the bottom side), 63 nets.

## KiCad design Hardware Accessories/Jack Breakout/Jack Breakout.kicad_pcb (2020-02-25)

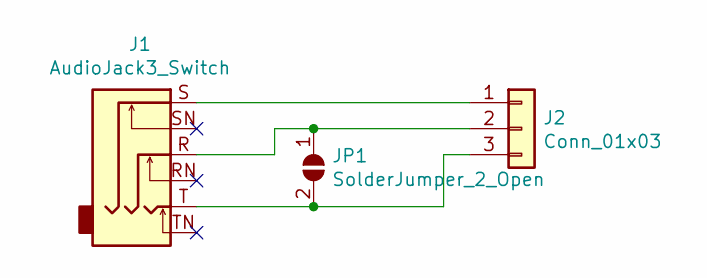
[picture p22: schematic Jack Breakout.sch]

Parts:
J1: AudioJack3_Switch; Jack_3.5mm_Neutrik_NMJ6HCD2_Horizontal
J2: Conn_01x03; Molex_KK-254_AE-6410-03A_1x03_P2.54mm_Vertical
JP1: SolderJumper_2_Open; SolderJumper-2_P1.3mm_Open_RoundedPad1.0x1.5mm

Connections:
unnamed: J1.R, J2.2, JP1.1 (A)
unnamed: J1.S, J2.1
unnamed: J1.T, J2.3, JP1.2 (B)

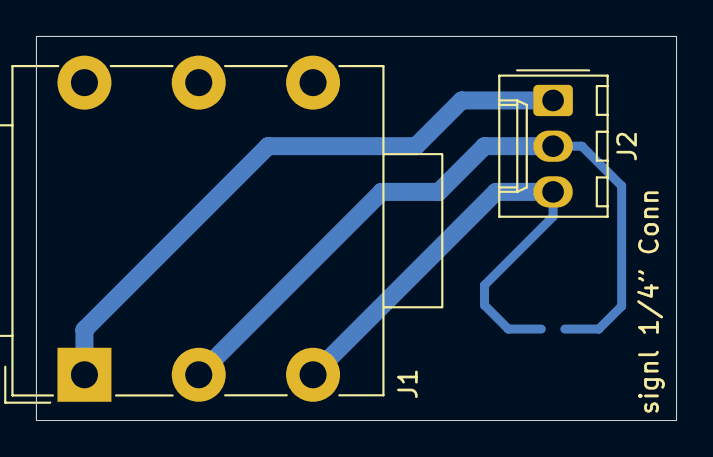
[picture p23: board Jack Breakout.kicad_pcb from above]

Board: 2 copper layers, 35.6 x 21.3 mm, 3 parts (1 on the bottom side), 3 nets.

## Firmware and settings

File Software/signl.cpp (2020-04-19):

#include "signl.h"
#include <iostream>
#include <stdexcept>
#include <cstring> //strerror()
#include <cmath>   //std::abs()

//Device names
const std::string GPIO = "/dev/gpiochip0";
const std::string SPI_ADC = "/dev/spidev0.0";
const std::string SPI_LCD = "/dev/spidev0.1";
//Pins
const auto LCD_A0    = 12;
const auto LCD_RES   = 13;
const auto JOY_UP    = 24;
const auto JOY_DOWN  = 26;
const auto JOY_LEFT  = 22;
const auto JOY_RIGHT = 25;
const auto JOY_PUSH  = 23;
const auto DEBOUNCE_TIME = 20;
//Flag to shutdown software
volatile sig_atomic_t signl::running = 0;

signl::signl() :
	//Base class
	jack_client("signl"),
	//Hardware
	display(SPI_LCD, GPIO, LCD_A0, LCD_RES),
	param(SPI_ADC),
	joy_up(GPIO, JOY_UP, false, DEBOUNCE_TIME, "JOY_UP"),
	joy_down(GPIO, JOY_DOWN, false, DEBOUNCE_TIME, "JOY_DOWN"),
	joy_left(GPIO, JOY_LEFT, false, DEBOUNCE_TIME, "JOY_LEFT"),
	joy_right(GPIO, JOY_RIGHT, false, DEBOUNCE_TIME, "JOY_RIGHT"),
	joy_push(GPIO, JOY_PUSH, false, DEBOUNCE_TIME, "JOY_PUSH"),
	//Effect manager
	effects("./effects"),
	//Effect selection index
	effect_idx(0),
	//Array of previous samples
	sample_array(),
	sample_array_idx(0),
	//FFT buffers
	tuner_array(),
	tuner_array_idx(0),
	fft_re(audiofft::AudioFFT::ComplexSize(gui::TUNER_BUFFER_LENGTH)),
	fft_im(audiofft::AudioFFT::ComplexSize(gui::TUNER_BUFFER_LENGTH)),
	//Parameter values
	param_val{0.0, 0.0, 0.0, 0.0},
	param_updated{false, false, false, false},
	//Input output gain
	in_level(1.0),
	out_level(1.0),
	//UI state
	state(EFFECT_CHAIN)
{
	//Register signal handlers
	struct sigaction s;
	s.sa_handler = sigterm_handler;
	s.sa_flags = SA_RESTART;
	sigemptyset(&s.sa_mask);
	if(sigaction(SIGTERM, &s, NULL))
		throw std::runtime_error("sigaction(): Could not register SIGTERM handler: " + std::string(strerror(errno)));
	if(sigaction(SIGINT, &s, NULL))
		throw std::runtime_error("sigaction(): Could not register SIGINT handler: " + std::string(strerror(errno)));

	//Print list of loaded plugins
	std::cout << "Loaded plugins:" << std::endl;
	for(auto &e : effects.list(rate()))
		std::cout << '\t' << e->name() << std::endl;

	//Create blank effect chain
	for(unsigned int i = 0; i < NUM_EFFECTS; i++)
	{
		effect_list lst(effects.list(rate()));
		effect_chain.push_back(std::move(lst));
	}

	//Initialise gaussian window
	for(unsigned int i = 0; i < gui::TUNER_BUFFER_LENGTH; ++i)
	{
		gauss.push_back(exp(-0.5*pow(0.4f*(i- ((gui::TUNER_BUFFER_LENGTH/2.0f)-1))/((gui::TUNER_BUFFER_LENGTH/2.0f)-1) ,2)));
	}

	running = 1;
	activate();
}

jack_client::sample_t signl::process(sample_t in)
{
	//Input gain, save for level display
	in *= in_level;
	sample_array[0][sample_array_idx] = in;

	//Store the input buffer for the tuner
	tuner_array[tuner_array_idx] = in;
	tuner_array_idx = (tuner_array_idx + 1) % gui::TUNER_BUFFER_LENGTH;

	//Process sample through effect chain, save intermediate results for level
	for(unsigned int i = 0; i < NUM_EFFECTS; i++)
	{
		in = effect_chain[i]()->process(in);
		sample_array[i+1][sample_array_idx] = in;
	}

	//Output gain, save for level display
	float out = in * out_level;
	sample_array[6][sample_array_idx] = out;

	//Loop array index (ring buffer)
	sample_array_idx = (sample_array_idx + 1) % gui::BUFFER_LENGTH;

	return out;
}

void signl::param_update()
{
	//For each parameter check if it has moved enough
	for(unsigned int i = 0; i < NUM_PARAMS; ++i)
	{
		//Read ADC
		float in = param(static_cast<adc::channel>(i));

		if(std::abs(in - param_val[i]) > 0.01)
		{
			//Save new value
			param_val[i] = in;
			param_updated[i] = true;
		}
	}
}

void signl::start()
{
	std::cout << "Starting..." << std::endl;
	while(running)
	{
		//Update parameters
		param_update();

		//User interface loop
		display.clear();

		//GUI states
		if(state == EFFECT_CHAIN)
		{
			//Change state
			if(joy_push)
				state = LEVEL_ADJ;

			//Update effect parameters
			for(unsigned int i = 0; i < NUM_PARAMS; i++)
			{
				if(param_updated[i])
					effect_chain[effect_idx]()->paramset(static_cast<effect::param>(i), param_val[i]);
			}

			//Joystick input
			if(joy_up)
				effect_chain[effect_idx]--;
			if(joy_down)
				effect_chain[effect_idx]++;
			if(joy_left)
			{
				effect_idx--;
				if (effect_idx >= NUM_EFFECTS)
					effect_idx = NUM_EFFECTS-1;
			}
			if(joy_right)
			{
				effect_idx++;
				effect_idx %= NUM_EFFECTS;
			}

			//Show parameter modify display
			display.param_view(effect_chain,effect_idx);
		}
		else if (state == LEVEL_ADJ)
		{
			//State change
			if(joy_push)
				state = TUNER;

			//Update input/output levels
			if(param_updated[0])
				in_level = 4*pow(param_val[0],2);
			if(param_updated[3])
				out_level = 4*pow(param_val[3],2);

			//Show sound level display
			display.level_view(in_level,out_level,sample_array);
		}
		else if (state == TUNER)
		{
			//State change
			if(joy_push)
				state = EFFECT_CHAIN;

			//Gaussian window the current tuner_array
			for(unsigned int i = 0; i < gui::TUNER_BUFFER_LENGTH; ++i)
				tuner_array[(tuner_array_idx + i) % gui::TUNER_BUFFER_LENGTH] *= gauss[i];

			//FFT the input sample buffer
			fft.init(gui::TUNER_BUFFER_LENGTH);
			fft.fft(tuner_array, fft_re.data(), fft_im.data());

			// find abs (store in re)
			for(unsigned int i = 0; i < fft_re.size(); ++i)
				fft_re[i] = sqrt(pow(fft_re[i],2)+pow(fft_im[i],2));

			// Show the tuner view
			display.tuner_view(fft_re.data());
		}

		//Reset param update flags, update display
		for(unsigned int i = 0; i < NUM_PARAMS; i++)
			param_updated[i] = false;
		display.signl_view(effect_chain);
		display.flip();
	}
	deactivate();
	std::cout << "Stopping..." << std::endl;
}

void signl::shutdown()
{
	running = 0;
}

void signl::sigterm_handler(int sig)
{
	running = 0;
}

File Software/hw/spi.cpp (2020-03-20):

#include "spi.h"
#include <stdexcept>
#include <cstring>     //strerror()
#include <sys/types.h> //open()
#include <sys/stat.h>  //open()
#include <fcntl.h>     //open()
#include <unistd.h>    //close()
#include <sys/ioctl.h> //ioctl()

spidev::spidev(std::string spidev, modes m, uint8_t bpw, uint32_t speed)
{
	//Open device
	fd = open(spidev.c_str(), O_RDWR | O_NONBLOCK);
	if(fd < 0)
		throw std::runtime_error("Could not open " + spidev + ": " + std::string(strerror(errno)));

	//Set parameters
	setmode(m);
	setbpw(bpw);
	setmaxspeed(speed);
}

void spidev::setmode(modes m)
{
	if(ioctl(fd, SPI_IOC_WR_MODE32, &m) < 0)
		throw std::runtime_error("Could not set spidev mode: " + std::to_string(m));
}

void spidev::setbpw(uint8_t bpw)
{
	if(ioctl(fd, SPI_IOC_WR_BITS_PER_WORD, &bpw) < 0)
		throw std::runtime_error("Could not set spidev bits per word: " + std::to_string(bpw));
}

void spidev::setmaxspeed(uint32_t speed)
{
	if(ioctl(fd, SPI_IOC_WR_MAX_SPEED_HZ, &speed) < 0)
		throw std::runtime_error("Could not set spidev speed: " + std::to_string(speed));
}

void spidev::xfer(const void *send, void *recv, uint32_t len)
{
	struct spi_ioc_transfer msg[1] = {};

	//Setup transmit and recieve buffers
	msg[0].tx_buf = reinterpret_cast<__u64>(send);
	msg[0].rx_buf = reinterpret_cast<__u64>(recv);
	msg[0].len = len;
	//Zeros here use default values from constructor
	msg[0].speed_hz = 0;
	msg[0].bits_per_word = 0;
	msg[0].tx_nbits = 0;
	msg[0].rx_nbits = 0;
	//Deselect device after transfer
	msg[0].cs_change = 0;
	//No delays between transfers
	msg[0].delay_usecs = 0;

	//Start transfer
	if(ioctl(fd, SPI_IOC_MESSAGE(1), msg) < 0)
		throw std::runtime_error("Could not read/write to spidev: " + std::string(strerror(errno)));
}

void spidev::xfer(void *buf, uint32_t len)
{
	xfer(buf, buf, len);
}

void spidev::send(const void *buf, uint32_t len)
{
	xfer(buf, nullptr, len);
}

void spidev::recv(void *buf, uint32_t len)
{
	xfer(nullptr, buf, len);
}

spidev::spidev(spidev&& other)
{
	fd = other.fd;
	other.fd = -1;
}

spidev& spidev::operator=(spidev&& other)
{
	if(this != &other)
	{
		close(fd);
		fd = other.fd;
		other.fd = -1;
	}
	return *this;
}

spidev::~spidev()
{
	close(fd);
}

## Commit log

2020-02-12 Initial commit of hardware.
    [Hardware.kicad_pcb, Hardware.sch]
2020-02-12 Added schematic symbol for JS5208 Joystick
2020-02-12 Added schematic symbol for WM8731SEDS
2020-02-12 Added schematic symbol for DOGM128W-6
2020-02-12 Added footprint for DOGM128W-6 LCD Screen
2020-02-12 Started schematic, added RPi, Joystick and ControlADC
    [Hardware.sch]
2020-02-14 Added WM8731SEDS to schematic and connected all relevant external circuitry, modified WM8731SEDS schematic part to aid routing
    [Hardware.sch]
2020-02-17 Connected WM8731SEDS audio codec to Raspberry Pi through I2S
    [Hardware.sch]
2020-02-17 Added DOGM128W-6 LCD Screen to schematic with supporting circutiry, corrected error in DOGM128W-6 Schematic part
    [Hardware.sch]
2020-02-17 Organised schematic sheet
    [Hardware.sch]
2020-02-18 Connected WM8731SEDS control interface through i2c to Raspberry Pi, finished connection of all systems
    [Hardware.sch]
2020-02-18 Created footprint for JS5208 Joystick
2020-02-19 Assigned PCB footprints to schematic symbols
    [Hardware.sch]
2020-02-19 Exported schematic sheet as PDF
2020-02-19 Changed to using 3-pin connectors for LINEIN and HP. Footprint associations, Schematic PDF, Netlist updated.
    [Hardware.sch]
2020-02-19 Started jack breakout CAD.
    [Jack Breakout.kicad_pcb, Jack Breakout.sch]
2020-02-19 Added .ipynb_checkpoints to .gitignore; finished 1/4" jack connector pending review; started exploratory physical design .ipynb
    [Jack Breakout.kicad_pcb]
2020-02-21 Began layout and routing of PCB, generated files to allow use of FreeRouting
    [Hardware.dsn, Hardware.kicad_pcb, Hardware.sch]
2020-02-23 Add simple null effect chain.
2020-02-25 Fixed jack breakout misalignment
    [Jack Breakout.sch]
2020-02-25 Cleaned up tracks on Jack Breakout
    [Jack Breakout.kicad_pcb]
2020-02-25 Printed traces for manufacture of jack breakout.
    [Jack Breakout.kicad_pcb]
2020-02-25 Routed main PCB
    [Hardware.dsn, Hardware.kicad_pcb]
2020-02-25 Added signl logo silkscreen to signl.pretty library.
2020-02-25 Cleaned up traces, organised silkscreen, stitched ground planes.
    [Hardware.dsn, Hardware.kicad_pcb]
2020-02-25 Added joystick 3d model to part.
    [Hardware.kicad_pcb]
2020-02-25 Moved I2C lines, added mounting holes, took renders.
    [Hardware.kicad_pcb]
2020-02-25 Added JLC serial code, created gerbers of main PCB.
    [Hardware-B_Cu.gbr, Hardware-B_Mask.gbr, Hardware-B_SilkS.gbr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]
2020-02-27 Add SPI device class.
2020-02-27 Add LCD driver class.
2020-02-27 Created .step file of PCB.
2020-02-28 Started design of enclosure.
    [Enclosure.SLDASM, Faceplate.SLDPRT, Hardware.SLDASM]
2020-02-28 Add constants for LCD pin numbers.
2020-02-29 Add ADC driver class.
2020-02-29 Initialize ADC in main application.
2020-03-02 Fix whitespace (spaces to tabs).
    [adc.cpp]
2020-03-02 Added clearances for parts, adjusted some dimensions
    [Faceplate.SLDPRT]
2020-03-02 Found accurate model of Raspberry Pi 3b+
2020-03-02 Designed box to be 3D printed and attach to Faceplate, will enclose raspberry pi and signl electronics.
    [Box.SLDPRT]
2020-03-02 Designed assembly using parts, generated .DXF files to be lasercut.
    [FaceplateBACK.DXF, FaceplateFRONT.DXF]
2020-03-04 Fix zero initilization of spi_ioc_transfer struct.
    [spi.cpp]
2020-03-04 Designed 'button' for use with JS5208 Joystick, included .STL for 3D printing.
    [JoystickButton.SLDPRT, JoystickButton.STEP, JoystickButton.STL]
2020-03-05 Print list of loaded plugins on startup.
2020-03-06 Modified Faceplate design to accomodate panelmount components better, Exported .DXFs
    [Faceplate.SLDPRT, FaceplateBACK.DXF, FaceplateFRONT.DXF]
2020-03-09 Fix req_gpio() always requesting an input pin.
    [gpio.cpp]
2020-03-10 Designed Faceplate graphics to be printed on viynl.
2020-03-17 Made schematic symbol for CO4305-12.000 External Oscillator.
2020-03-17 Designed PCB footprint for CO4305-12.000 External Oscillator.
2020-03-17 Added external oscillator to Schematic and PCB. Plotted outputs.
    [Hardware-B_Cu.gbr, Hardware-B_Mask.gbr, Hardware-B_SilkS.gbr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]
2020-03-19 Pi (#25)
    * Fit effect line to screen.
    * Printing effect chain to gui.
    * Added parameter printing.
2020-03-20 Return unsigned int from effect manager, fixes sign comparison warning.
    [signl.cpp]
2020-03-20 Pass sample rate to effect manager.
2020-03-20 Pass sample rate to plugin creation function.
2020-03-20 Pass sample rate to effect constructors.
2020-03-20 Remove hard coded sample rate from noise gate plugin.
2020-03-20 Fixed ADC SPI chip select bug.
    [adc.cpp, spi.cpp]
2020-03-20 Knobs change effect parameters when they have been moved by 3% to eliminate noise and so that each effect in the chain can 'hold' it's parameters when the user scrolls left and right through the chai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
    [signl.cpp]
2020-03-23 Moved references for R15 and R19 to correct place.
    [Hardware.kicad_pcb]
2020-03-24 Started the level adjustment screen. Needs tidying and isn't fully tested as jack started having issues.
    [signl.cpp]
2020-03-29 Fix zero initialization warning.
    [signl.cpp]
2020-03-29 Add documentation for adc class.
2020-03-31 Added eq biquad filter and filter coefficients.:
2020-03-31 Modifying filter coeffs to make all 1st order butter filters.
2020-04-01 Use 2nd order filter in eq.cpp low and high pass filters.
2020-04-01 Add python script to generate and plot eq filter responces.
2020-04-02 Added a thread to handle the convolution processing.
2020-04-05 Add documentation for spi class.
2020-04-09 Tried to add filter.
2020-04-09 Added cut option.
2020-04-09 Neatened filter.
2020-04-10 Deactivate JACK client on exit.
    This fixes random segfaults that occur when the program is closed.
    This occured due to the JACK process callback still being called
    during destruction of objects, leading to dangling pointers, or
    pure virtual functions being called.
    [signl.cpp]
2020-04-10 Finished vinyl effect, adding the filter and dry-wet parameters.
2020-04-11 Disable PWM sound card.
2020-04-11 Fix missing bracket in script.
2020-04-13 Fixed parameter update bug which only allowed Param A of effect 1, Param B of effect 2 etc... to be updated.
    [signl.cpp]
2020-04-14 Use effect_manager::list() when printing plugins at start.
2020-04-14 Do not delete effect when they are switched out.
2020-04-14 Swapped up and down joystick effect.
    [signl.cpp]
2020-04-14 Add effect chain diagram.
2020-04-15 Generated bill of materials to aid reproducability.
2020-04-17 Assigned datasheets and supplier links to all schematic components. Regenerated BoM.
    [Hardware.kicad_pcb, Hardware.sch]
2020-04-17 Added cropped schematic sections.
2020-04-17 Re-made renders of PCB.
    [Hardware.kicad_pcb]
2020-04-18 Rendered enclosure and full setup, made drawing showing rack unit dimensions.
2020-04-18 Exported model for box in numerous formats for most compatibility.
    [Box.SLDPRT, Box.STEP, Box.STL]
2020-04-18 Fixed tuner array not being used.
    [signl.cpp]
2020-04-18 Added images of realPCB and assembly.
